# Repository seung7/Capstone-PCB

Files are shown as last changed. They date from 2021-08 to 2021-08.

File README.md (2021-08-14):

# PCB for Capstone Project

## Goal
Our Capstone Project MUP(Monitoring Unoccupied Property) should be able to work when a power outrage is happened. To achieve this, we require a PCB that can automatically switch to the battery power when the power outrage is happened. In other words, the PCB should work as UPS(Uninterruptible Power Supply)

## Requirements
1. PCB should deliver minimum of 5V, 2.5A (12.5W) to MUP 

| Components in MUP | Amp |
| --- |:---:|
| Raspberry Pi 4B at maximum load (400% CPU Usages) | 1280mA
| Camera | 400mA | 
| MangOH Yellow | 500mA |
| Keyboard & Mouse | 100mA |
| HDMI | 50mA|
| | |
| Total| 2330mA |

2. PCB should be able to recharge the custom 18650 battery pack: https://www.batteryspace.com/custom-li-ion-18650-battery-3-635v-28ah-101-78wh-7a-rate-2x4s-s-inr18650-mj1.aspx  and MUP in a same time, when the 5.1V 3A wall power adapter: https://www.raspberrypi.org/products/type-c-power-supply/ is plugged in
3. PCB should use USB-C as both input and output

## Open Source 
We have found the Open Source PCB created by CRAIG PEACOCK, which satisfies our requirements:
https://workspace.circuitmaker.com/Projects/Details/Craig-Peacock-4/5V-Uninterruptable-Power-Supply-USB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

## Modification
1. Change of R1. 

We need the total input current to be 3.5A so that when the AC adaptor is pluged, MUP can draw a full 2.5A while the remaining 1A will be used to charge the battery at the same time. The current of the circuit can be altered by R1. By modifying R1 from 0.01ohm to 0.007ohm, the circuit can provide 0.025v/0.007 = 3.5A rather than 0.025v/0.01 = 2.5A.

2. Bigger battery pack.

The original design uses two 18650 batteries, that gives 4400mAh. That would only last for 4400mAh/2330mA = 1.8 hours. However our MUP should be ready for power outrages more than 6 hours. For that reason we have purchased 28000mAh customized battery pack providing 28000mAh/2330mA = 12 hours. To establish the connection, the battery's wires connected to its terminals are soldered into the PCB like the image below:

## Simulation
LTC4040 was used by CRAIGPEACOCK for the power management but, but LTSpice does not have the exact model. So we have tested with LTC4412 which also used for UPS. 
Using the DC sweep, the wall power is dropped from 5v to 0v in the simulation, and currents for the wall power and the battery are measured. 
<p align="center">
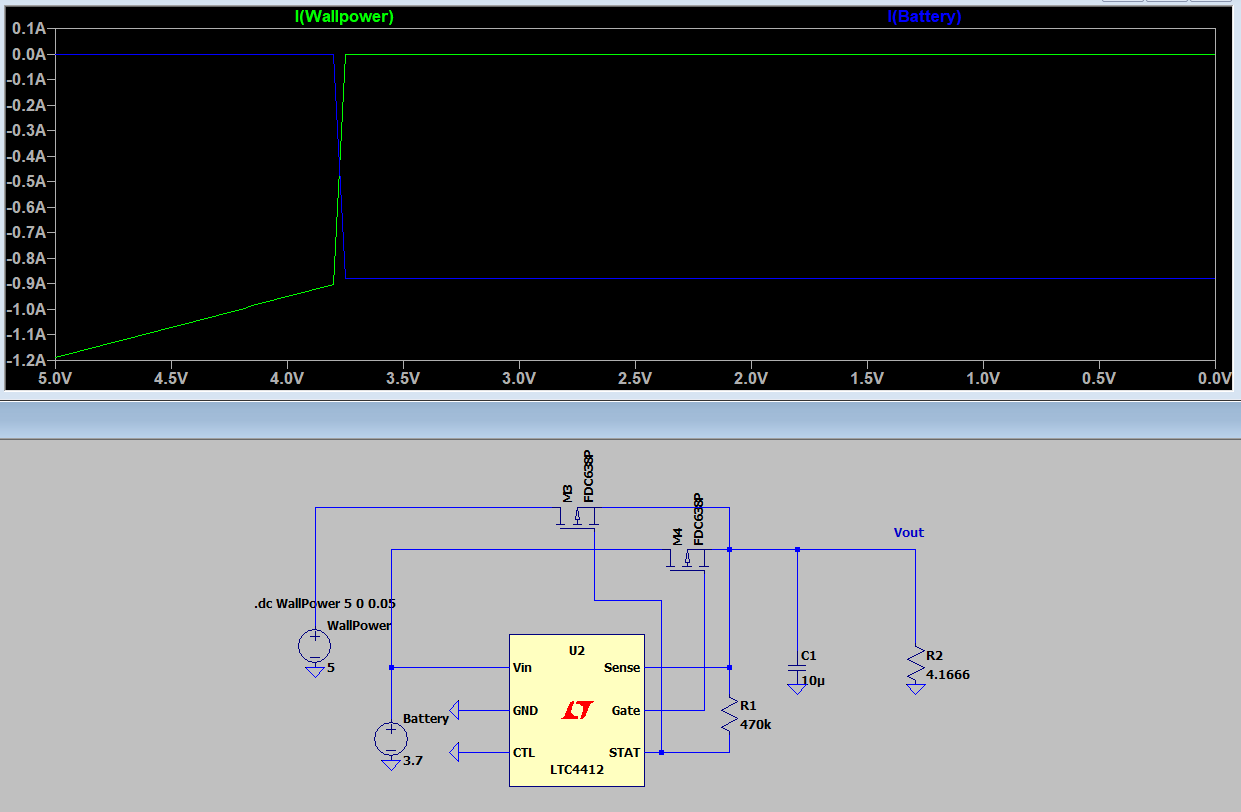
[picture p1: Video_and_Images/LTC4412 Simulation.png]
   
</p>
As soon as the current from the wall dropped, the current in the battery raised. So the simulation was successful. 

## Procedure
The PCB was designed through PCBWAY https://www.pcbway.com/

The components were ordered from digikey https://www.digikey.ca/, mouser https://www.mouser.ca/, newark https://canada.newark.com/

PCBWAY not only make PCB but also provide assembly service. However, due to the time limit of the project, we ordered all the components and send the assembly order to the local company. We have contacted Maxtech and was able to get a PCB assembled within a week.

## Result
Our Raspberry Pi did not lose the power when we turn off the AC power outlet swtich. Our PCB successfully switches the power from the wall outlet to the battery pack.

<p align="center">
   
</p>

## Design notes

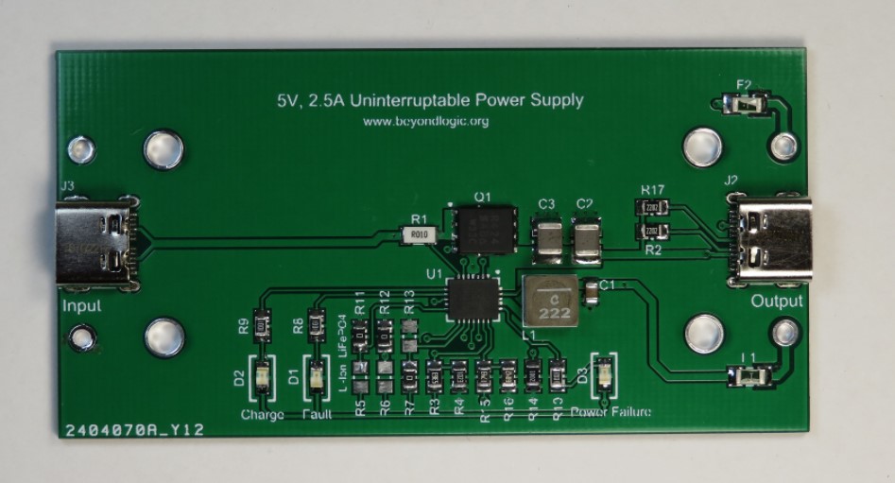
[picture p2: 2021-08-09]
PMS screenshot.jpg

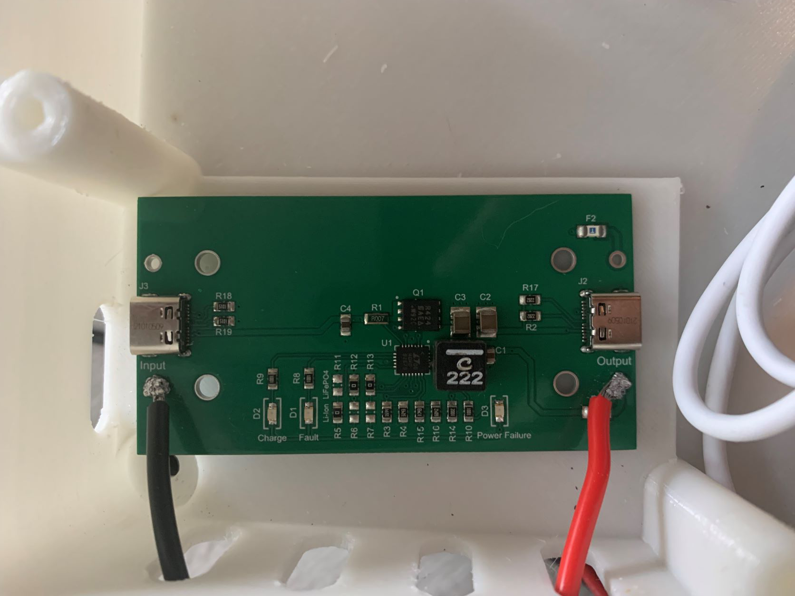
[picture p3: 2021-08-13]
Video_and_Images/PMS_image.jpg

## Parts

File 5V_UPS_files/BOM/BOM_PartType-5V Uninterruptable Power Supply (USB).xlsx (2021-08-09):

Comment | Description | Designator | Footprint | LibRef | Quantity
10uF 6.3V | Cap Ceramic 10uF 6.3V X7R 10% SMD 0805 125°C Embossed T/R | C1 | PCB-jc9lkjqzzknv4ogtkgcu-1 | CMP-e7812e33bfa43846-1 | 1
100uF | Samsung Electro-Mechanics 100F 20% 10 V X5R Dielectric SMD Ceramic Multilayer Capacitor 1210 | C2, C3 | CAPC3225X280X60ML40T30 | CMP-9010136-2 | 2
2.2uF | 0805 2.2 uF 25 V ±10 % Tolerance X5R SMT Multilayer Ceramic Capacitor | C4 | CAPC2013X145X50ML20T25 | CMP-7e2cb7ab90b4a1eb-1 | 1
Lite-On LTST-C170KRKT | Red 2 x 1.25 x 1.1 mm 130° Water Clear 54 mcd 2 V LED Surface Mount | D1, D2, D3 | PCB-5ta9mte2am12bu12jwvi-1 | CMP-1544870-4 | 3
5A | Fuse Chip Fast Acting 5A 32V SMD Solder Pad 1206 Ceramic T/R CSA/UL | F1, F2 | RESC3216X70X50ML20T25 | CMP-475d8ed45800989a-3 | 2
Molex 105450-0101 | USB Shielded I/O Receptacle; Type C; Right Angle; Surface Mount; Gold over Nickel | J2, J3 | PCB-zb4thd4mh8xiiqufiqw2-1 | CMP-36bdfbb9c94ee97a-1 | 2
2.2uH | Power inductor, shielded, 20% tol, SMT, RoHS, halogen-f | L1 | PCB-eh2uh0b1ckxc83nsi4qq-1 | CMP-6312ab38135cbcd5-5 | 1
SIR424DP-T1-GE3 | SiR172DP Series N-Channel 20 V 0.0074 Ohm 41.7 W SMT Mosfet - PowerPAK® SO-8 | Q1 | PCB-12911244-1 | CMP-5ad092fae9868517-5 | 1
0.007 | RES SMD 0.007 OHM 1% 1W 1632 | R1 | PCB-19418829-1 | CMP-19418829-1 | 1
22K | Res Thick Film 0805 22K Ohm 1% 0.125W(1/8W) ±100ppm/C Epoxy Pad SMD T/R | R2, R17 | RESC2013X60X35ML10T20 | CMP-3ca3f7cba413e364-2 | 2
1.69M | RES SMD 1.69M OHM 1% 1/8W 0805 | R3 | RESC2013X60X35ML10T20 | CMP-1866135-2 | 1
324K | RES SMD 324K OHM 1% 1/8W 0805 | R4 | RESC2013X60X35ML10T20 | CMP-1875618-2 | 1
0 | Res Thick Film 0805 0 Ohm Molded SMD Paper T/R | R5, R12, R13 | RESC2013X60X35ML10T20 | CMP-1875921-8 | 3
1K | RC Series 0805 0.125 W 1 kOhms 1% ±100 ppm/°C SMT Thick Film Chip Resistor | R8, R9, R10 | RESC2013X60X35ML10T20 | CMP-1854304-19 | 3
2K | Res Thick Film 0805 2K Ohm 1% 0.125W(1/8W) ±100ppm/C Epoxy Pad SMD T/R | R14 | RESC2013X60X35ML10T20 | CMP-52aa99c2ca168d6d-4 | 1
174K | RES SMD 174K OHM 1% 1/8W 0805 | R15 | RESC2013X60X35ML10T20 | CMP-1872060-2 | 1
60K4 | RC Series 0805 0.125 W 60.4 kOhms 1% ±100 ppm/°C SMT Thick Film Chip Resistor | R16 | RESC2013X60X35ML10T20 | CMP-bfd776c8b5e36010-1 | 1
5K1 | Res Thick Film 0805 5.1K Ohm 1% 0.125W(1/8W) ±100ppm/C Epoxy Pad SMD T/R | R18, R19 | RESC2013X60X35ML10T20 | CMP-9b27523ffbe444e0-2 | 2
LTC4040EUFD#PBF | LTC4040 - 2.5A Battery Backup Power Manager | U1 | LT-UFD-24_M | CMP-214aebc9e294fe8d-2 | 1

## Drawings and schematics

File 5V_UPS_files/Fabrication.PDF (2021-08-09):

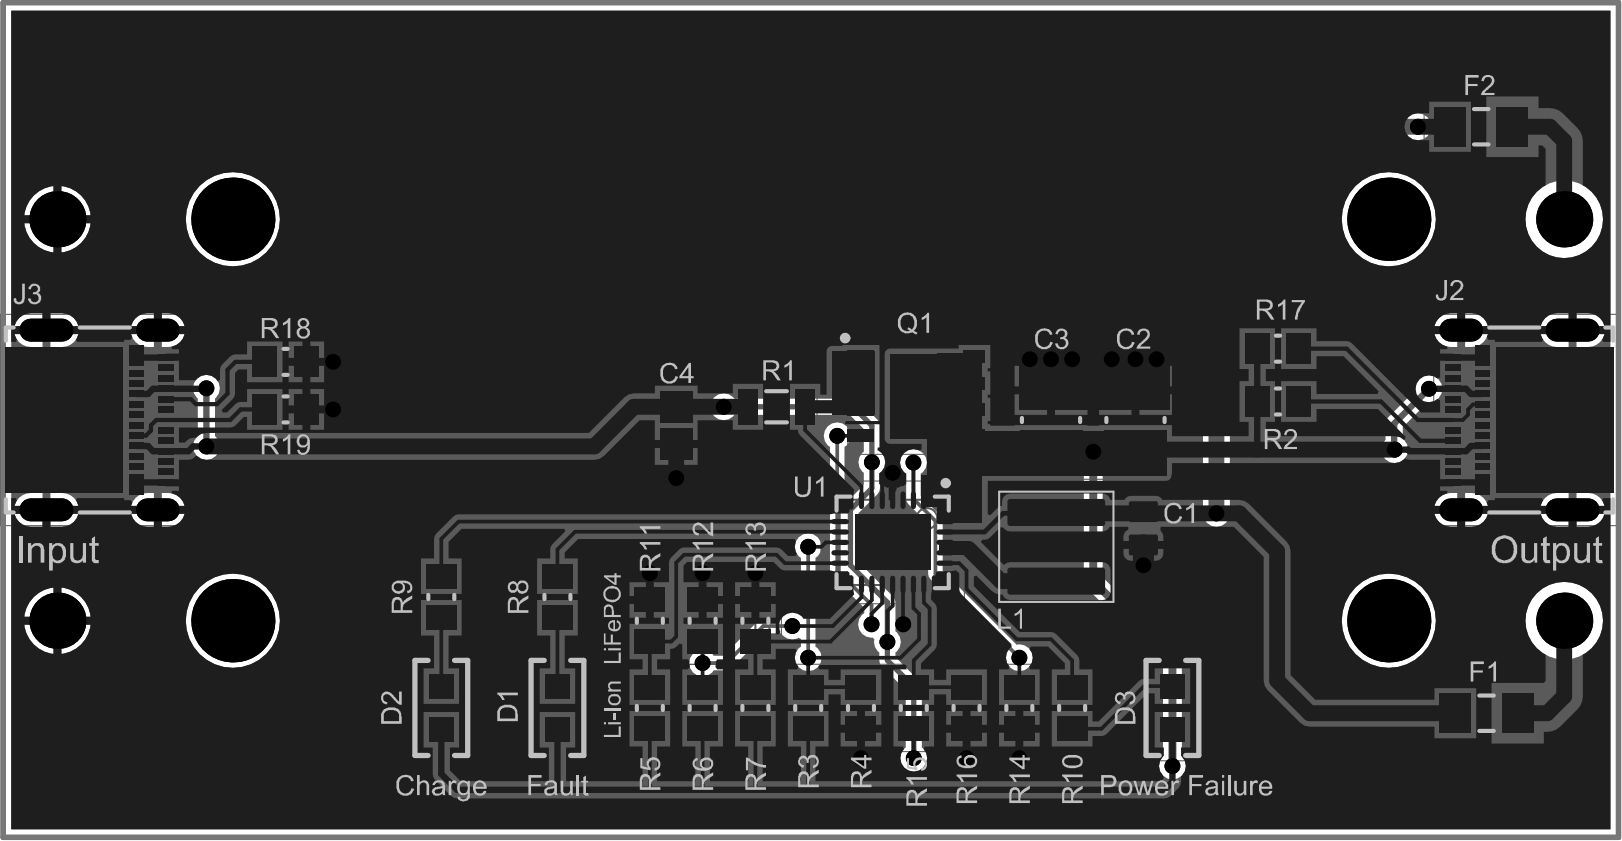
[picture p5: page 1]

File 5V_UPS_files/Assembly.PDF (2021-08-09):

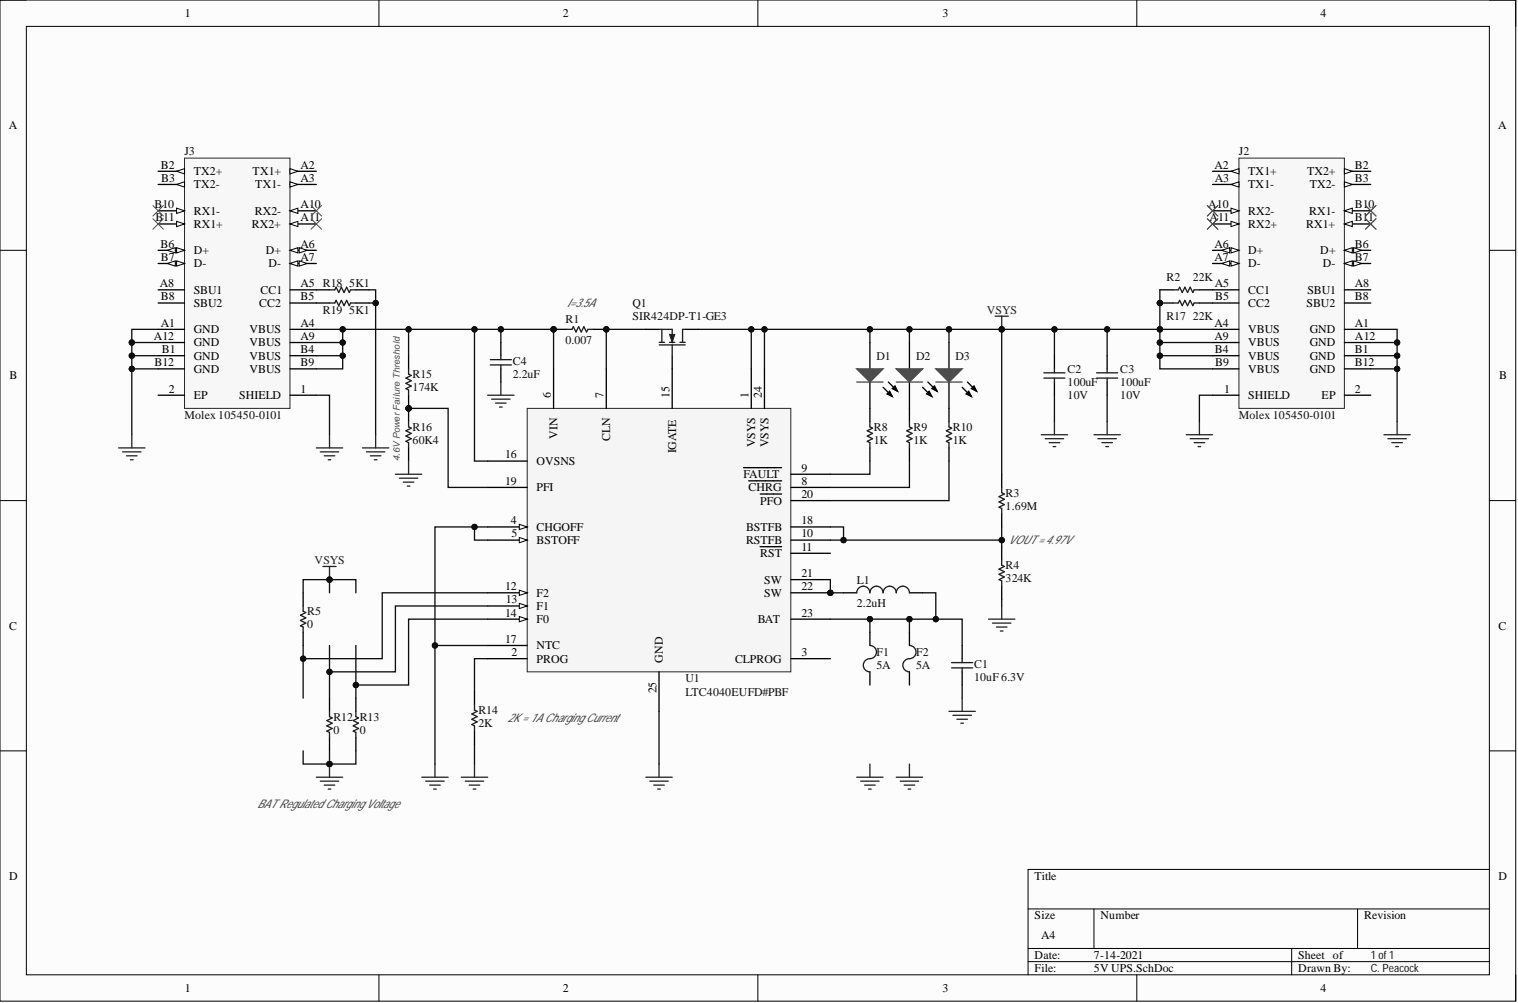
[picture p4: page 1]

1 3
1 4
